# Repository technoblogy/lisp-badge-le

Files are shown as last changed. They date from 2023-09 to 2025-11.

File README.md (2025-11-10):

# Lisp Badge LE
A self-contained low-power computer with its own display and keyboard that you can program in Lisp. It now includes autocomplete, together with the new features in uLisp Release 4.8f.

The files are as follows:

* LispBadgeLE.ino - the uLisp source file for the Lisp Badge LE.
* LispBadgeLE-comments.ino - identical but including comprehensive comments.

Only use one of these files. It should be compiled and uploaded using the Arduino IDE.

For more information see http://www.technoblogy.com/show?3Z2Y.

Note that for consistency with the previous version of the Lisp Badge LE, autocomplete has been assigned to **META-ESC**. If you think that it would be more convenient to have autocomplete on **ESC** and Escape on **META-ESC**, swap the occurrences of '\e' and '\t' in **Keymap[]** before uploading uLisp.

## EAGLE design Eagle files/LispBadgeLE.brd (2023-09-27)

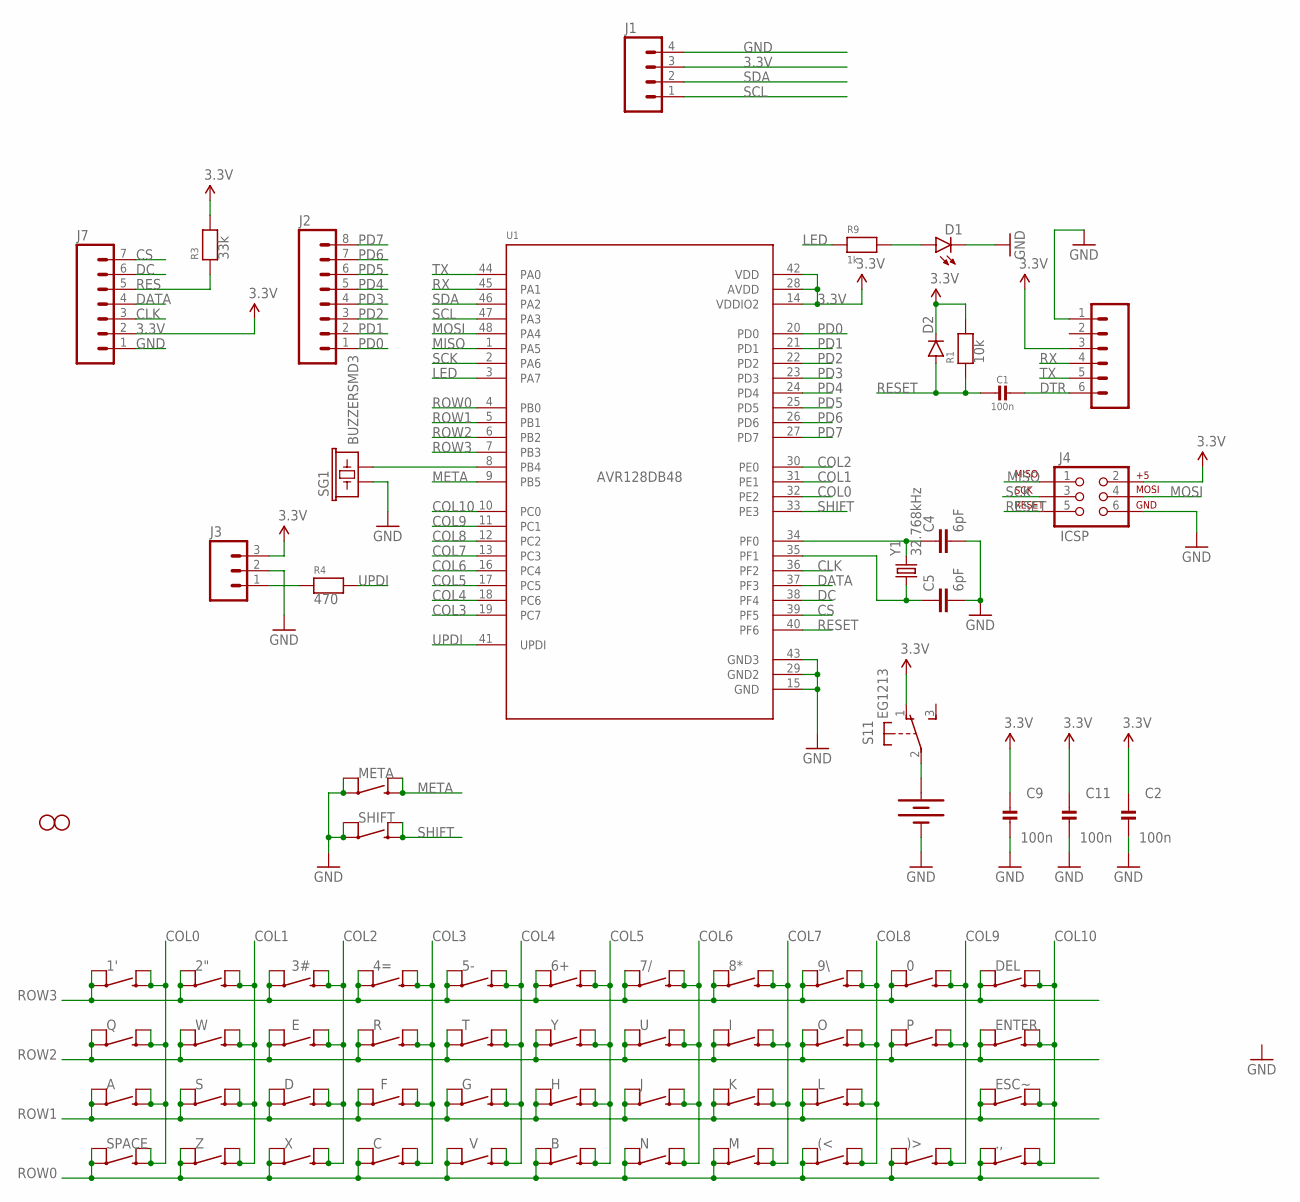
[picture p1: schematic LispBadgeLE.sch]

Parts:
0, 1', 2", 3#, 4=, 5-, 6+, 7/, 8*, 9\\, .,: SWITCH-MOMENTARY-2SMD-4; TACTILE_SWITCH_TALL
(<: SWITCH-MOMENTARY-2SMD-4; TACTILE_SWITCH_TALL
)>: SWITCH-MOMENTARY-2SMD-4; TACTILE_SWITCH_TALL
A: SWITCH-MOMENTARY-2SMD-4; TACTILE_SWITCH_TALL
B: SWITCH-MOMENTARY-2SMD-4; TACTILE_SWITCH_TALL
BAT1: 20mm coincell; BATTCON_20MM_4LEGS
C: SWITCH-MOMENTARY-2SMD-4; TACTILE_SWITCH_TALL
C1, C2, C9, C11: 100n; _0805MP
C4, C5: 6pF; 0805
D: SWITCH-MOMENTARY-2SMD-4; TACTILE_SWITCH_TALL
D1: LED1206-BOTTOM; LED-1206-BOTTOM
D2: DIODESOD123; SOD-123
DEL: SWITCH-MOMENTARY-2SMD-4; TACTILE_SWITCH_TALL
E: SWITCH-MOMENTARY-2SMD-4; TACTILE_SWITCH_TALL
ENTER: SWITCH-MOMENTARY-2SMD-4; TACTILE_SWITCH_TALL
ESC~: SWITCH-MOMENTARY-2SMD-4; TACTILE_SWITCH_TALL
F: SWITCH-MOMENTARY-2SMD-4; TACTILE_SWITCH_TALL
G: SWITCH-MOMENTARY-2SMD-4; TACTILE_SWITCH_TALL
H: SWITCH-MOMENTARY-2SMD-4; TACTILE_SWITCH_TALL
I: SWITCH-MOMENTARY-2SMD-4; TACTILE_SWITCH_TALL
J: SWITCH-MOMENTARY-2SMD-4; TACTILE_SWITCH_TALL
J1: M04LONGPADS; 1X04_LONGPADS
J2: M08LONGPADS; 1X08_LONGPADS
J3: M03LONGPADS; 1X03_LONGPADS
J4: ICSP; 2X3
J7: M07; 1X07
JP1: M06LONGPADS; 1X06_LONGPADS
JP4, JP5: STAND-OFF
K: SWITCH-MOMENTARY-2SMD-4; TACTILE_SWITCH_TALL
L: SWITCH-MOMENTARY-2SMD-4; TACTILE_SWITCH_TALL
M: SWITCH-MOMENTARY-2SMD-4; TACTILE_SWITCH_TALL
META: SWITCH-MOMENTARY-2SMD-4; TACTILE_SWITCH_TALL
N: SWITCH-MOMENTARY-2SMD-4; TACTILE_SWITCH_TALL
O: SWITCH-MOMENTARY-2SMD-4; TACTILE_SWITCH_TALL
P: SWITCH-MOMENTARY-2SMD-4; TACTILE_SWITCH_TALL
Q: SWITCH-MOMENTARY-2SMD-4; TACTILE_SWITCH_TALL
R: SWITCH-MOMENTARY-2SMD-4; TACTILE_SWITCH_TALL
R1: 10k; _0805MP
R3: 33k; _0805MP
R4: 470; _0805MP
R9: 1k; _0805MP
S: SWITCH-MOMENTARY-2SMD-4; TACTILE_SWITCH_TALL
S1: EG1213
SG1: BUZZERSMD3; BUZZER-CMT1102
SHIFT: SWITCH-MOMENTARY-2SMD-4; TACTILE_SWITCH_TALL
SPACE: SWITCH-MOMENTARY-2SMD-4; TACTILE_SWITCH_TALL
T: SWITCH-MOMENTARY-2SMD-4; TACTILE_SWITCH_TALL
U: SWITCH-MOMENTARY-2SMD-4; TACTILE_SWITCH_TALL
U1: AVR128DB48; LQFP48
V: SWITCH-MOMENTARY-2SMD-4; TACTILE_SWITCH_TALL
W: SWITCH-MOMENTARY-2SMD-4; TACTILE_SWITCH_TALL
X: SWITCH-MOMENTARY-2SMD-4; TACTILE_SWITCH_TALL
Y: SWITCH-MOMENTARY-2SMD-4; TACTILE_SWITCH_TALL
Y1: 32.768kHz; CRYSTAL-SMD-3.2X1.5MM
Z: SWITCH-MOMENTARY-2SMD-4; TACTILE_SWITCH_TALL

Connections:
3.3V: C2.1, C9.1, C11.1, D2.C, J1.3, J3.3, J4.2, J7.2, JP1.3, R1.2, R3.2, S1.1 (O), U1.14 (VDDIO2), U1.28 (AVDD), U1.42 (VDD)
CLK: J7.3, U1.36 (PF2)
COL0: 1'.B1 (4), 1'.B2 (2), A.B1 (4), A.B2 (2), Q.B1 (4), Q.B2 (2), SPACE.B1 (4), SPACE.B2 (2), U1.32 (PE2)
COL1: 2".B1 (4), 2".B2 (2), S.B1 (4), S.B2 (2), U1.31 (PE1), W.B1 (4), W.B2 (2), Z.B1 (4), Z.B2 (2)
COL2: 3#.B1 (4), 3#.B2 (2), D.B1 (4), D.B2 (2), E.B1 (4), E.B2 (2), U1.30 (PE0), X.B1 (4), X.B2 (2)
COL3: 4=.B1 (4), 4=.B2 (2), C.B1 (4), C.B2 (2), F.B1 (4), F.B2 (2), R.B1 (4), R.B2 (2), U1.19 (PC7)
COL4: 5-.B1 (4), 5-.B2 (2), G.B1 (4), G.B2 (2), T.B1 (4), T.B2 (2), U1.18 (PC6), V.B1 (4), V.B2 (2)
COL5: 6+.B1 (4), 6+.B2 (2), B.B1 (4), B.B2 (2), H.B1 (4), H.B2 (2), U1.17 (PC5), Y.B1 (4), Y.B2 (2)
COL6: 7/.B1 (4), 7/.B2 (2), J.B1 (4), J.B2 (2), N.B1 (4), N.B2 (2), U.B1 (4), U.B2 (2), U1.16 (PC4)
COL7: 8*.B1 (4), 8*.B2 (2), I.B1 (4), I.B2 (2), K.B1 (4), K.B2 (2), M.B1 (4), M.B2 (2), U1.13 (PC3)
COL8: 9\\.B1 (4), 9\\.B2 (2), (<.B1 (4), (<.B2 (2), L.B1 (4), L.B2 (2), O.B1 (4), O.B2 (2), U1.12 (PC2)
COL9: 0.B1 (4), 0.B2 (2), )>.B1 (4), )>.B2 (2), P.B1 (4), P.B2 (2), U1.11 (PC1)
COL10: .,.B1 (4), .,.B2 (2), DEL.B1 (4), DEL.B2 (2), ENTER.B1 (4), ENTER.B2 (2), ESC~.B1 (4), ESC~.B2 (2), U1.10 (PC0)
CS: J7.7, U1.39 (PF5)
DATA: J7.4, U1.37 (PF3)
DC: J7.6, U1.38 (PF4)
DTR: C1.1, JP1.6
GND: BAT1.NEGATIVE (-), C2.2, C4.2, C5.2, C9.2, C11.2, D1.C, J1.4, J3.2, J4.6, J7.1, JP1.1, META.A1 (3), META.A2 (1), SG1.1, SHIFT.A1 (3), SHIFT.A2 (1), U1.15 (GND), U1.29 (GND2), U1.43 (GND3)
LED: R9.1, U1.3 (PA7)
META: META.B1 (4), META.B2 (2), U1.9 (PB5)
MISO: J4.1, U1.1 (PA5)
MOSI: J4.4, U1.48 (PA4)
unnamed: C5.1, U1.35 (PF1), Y1.P$1 (1)
unnamed: C4.1, U1.34 (PF0), Y1.P$2 (2)
unnamed: D1.A, R9.2
unnamed: BAT1.POSITIVE@1 (+), BAT1.POSITIVE@2 (+), BAT1.POSITIVE@3 (+), BAT1.POSITIVE@4 (+), S1.2
unnamed: SG1.2, U1.8 (PB4)
unnamed: J3.1, R4.1
PD0: J2.1, U1.20 (PD0)
PD1: J2.2, U1.21 (PD1)
PD2: J2.3, U1.22 (PD2)
PD3: J2.4, U1.23 (PD3)
PD4: J2.5, U1.24 (PD4)
PD5: J2.6, U1.25 (PD5)
PD6: J2.7, U1.26 (PD6)
PD7: J2.8, U1.27 (PD7)
RES: J7.5, R3.1
RESET: C1.2, D2.A, J4.5, R1.1, U1.40 (PF6)
ROW0: (<.A1 (3), (<.A2 (1), )>.A1 (3), )>.A2 (1), .,.A1 (3), .,.A2 (1), B.A1 (3), B.A2 (1), C.A1 (3), C.A2 (1), M.A1 (3), M.A2 (1), N.A1 (3), N.A2 (1), SPACE.A1 (3), SPACE.A2 (1), U1.4 (PB0), V.A1 (3), V.A2 (1), X.A1 (3), X.A2 (1), Z.A1 (3), Z.A2 (1)
ROW1: A.A1 (3), A.A2 (1), D.A1 (3), D.A2 (1), ESC~.A1 (3), ESC~.A2 (1), F.A1 (3), F.A2 (1), G.A1 (3), G.A2 (1), H.A1 (3), H.A2 (1), J.A1 (3), J.A2 (1), K.A1 (3), K.A2 (1), L.A1 (3), L.A2 (1), S.A1 (3), S.A2 (1), U1.5 (PB1)
ROW2: E.A1 (3), E.A2 (1), ENTER.A1 (3), ENTER.A2 (1), I.A1 (3), I.A2 (1), O.A1 (3), O.A2 (1), P.A1 (3), P.A2 (1), Q.A1 (3), Q.A2 (1), R.A1 (3), R.A2 (1), T.A1 (3), T.A2 (1), U.A1 (3), U.A2 (1), U1.6 (PB2), W.A1 (3), W.A2 (1), Y.A1 (3), Y.A2 (1)
ROW3: 0.A1 (3), 0.A2 (1), 1'.A1 (3), 1'.A2 (1), 2".A1 (3), 2".A2 (1), 3#.A1 (3), 3#.A2 (1), 4=.A1 (3), 4=.A2 (1), 5-.A1 (3), 5-.A2 (1), 6+.A1 (3), 6+.A2 (1), 7/.A1 (3), 7/.A2 (1), 8*.A1 (3), 8*.A2 (1), 9\\.A1 (3), 9\\.A2 (1), DEL.A1 (3), DEL.A2 (1), U1.7 (PB3)
RX: JP1.4, U1.45 (PA1)
SCK: J4.3, U1.2 (PA6)
SCL: J1.1, U1.47 (PA3)
SDA: J1.2, U1.46 (PA2)
SHIFT: SHIFT.B1 (4), SHIFT.B2 (2), U1.33 (PE3)
TX: JP1.5, U1.44 (PA0)
UPDI: R4.2, U1.41 (UPDI)

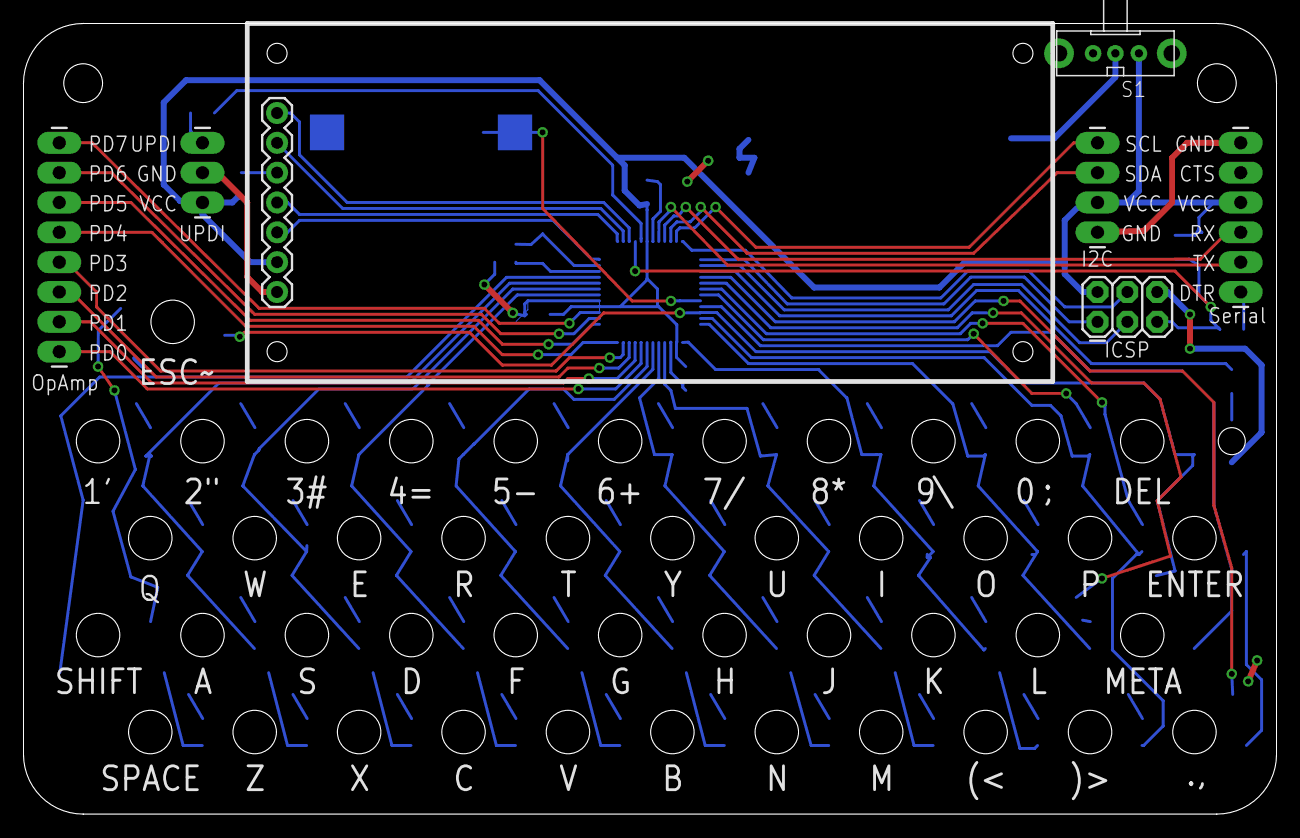
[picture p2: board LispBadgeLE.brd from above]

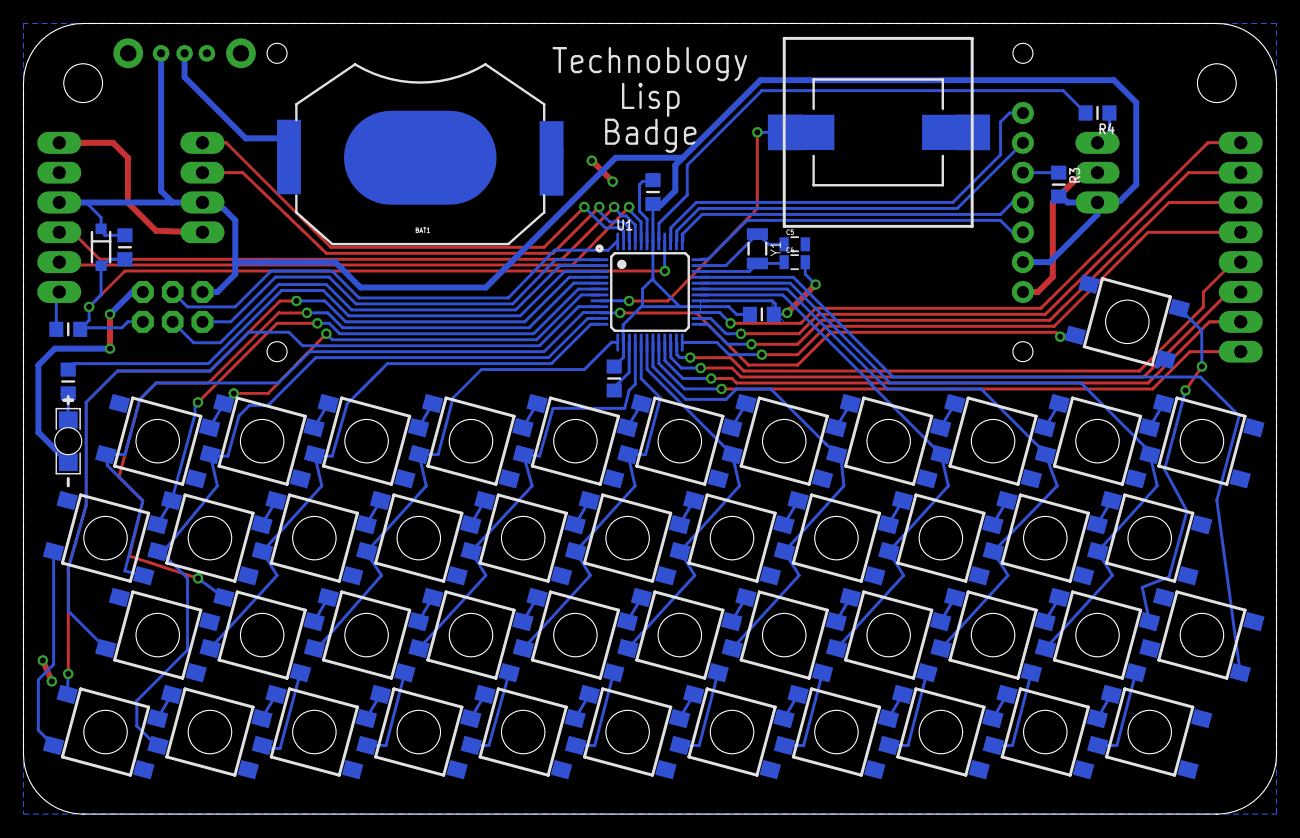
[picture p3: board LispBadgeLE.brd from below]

Board: 2 copper layers, 106.7 x 67.3 mm, 70 parts (61 on the bottom side), 49 nets.

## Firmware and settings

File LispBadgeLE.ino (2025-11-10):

/* Lisp Badge LE Release 4.8f - www.ulisp.com
   David Johnson-Davies - www.technoblogy.com - 9th November 2025

   Licensed under the MIT license: https://opensource.org/licenses/MIT
*/

// Lisp Library
const char LispLibrary[] PROGMEM = "";

// Compile options

#define checkoverflow
// #define resetautorun
#define printfreespace
#define serialmonitor
// #define printgcs
// #define sdcardsupport
// #define lisplibrary
#define assemblerlist
// #define extensions

// Includes

// #include "LispLibrary.h"
#include <avr/sleep.h>
#include <setjmp.h>
#include <SPI.h>
#include <limits.h>

#if defined(sdcardsupport)
#include <SD.h>
#define SDSIZE 172
#else
#define SDSIZE 0
#endif

// Platform specific settings

#define WORDALIGNED __attribute__((aligned (2)))
#define OBJECTALIGNED __attribute__((aligned (4)))
#define BUFFERSIZE 22                     /* longest builtin name + 1 */

#if defined(__AVR_AVR128DA48__) || defined(__AVR_AVR128DB48__)  /* LispBadge LE */
  #include <Flash.h>
  #define WORKSPACESIZE (2795-SDSIZE)     /* Objects (4*bytes) */
  #define FLASHWRITESIZE 16384            /* Bytes */
  #define CODESIZE 96                     /* Bytes <= 512 */
  #define STACKDIFF 320
  #define CPU_AVR128DX48
  #undef  LED_BUILTIN
  #define LED_BUILTIN 7
  #define SDCARD_SS_PIN 10
  #define SHIFT_KEY 33
  #define META_KEY 13
  const uint8_t xsize = 250, ysize = 122, ymax = 121;

#else
#error "Board not supported!"
#endif

// C Macros

#define nil                NULL
#define car(x)             (((object *) (x))->car)
#define cdr(x)             (((object *) (x))->cdr)

#define first(x)           car(x)
#define rest(x)            cdr(x)
#define second(x)          first(rest(x))
#define cddr(x)            cdr(cdr(x))
#define third(x)           first(cddr(x))

#define push(x, y)         ((y) = cons((x),(y)))
#define pop(y)             ((y) = cdr(y))

#define protect(y)         push((y), GCStack)
#define unprotect()        pop(GCStack)

#define integerp(x)        ((x) != NULL && (x)->type == NUMBER)
#define symbolp(x)         ((x) != NULL && (x)->type == SYMBOL)
#define stringp(x)         ((x) != NULL && (x)->type == STRING)
#define characterp(x)      ((x) != NULL && (x)->type == CHARACTER)
#define arrayp(x)          ((x) != NULL && (x)->type == ARRAY)
#define streamp(x)         ((x) != NULL && (x)->type == STREAM)

#define mark(x)            (car(x) = (object *)(((uintptr_t)(car(x))) | MARKBIT))
#define unmark(x)          (car(x) = (object *)(((uintptr_t)(car(x))) & ~MARKBIT))
#define marked(x)          ((((uintptr_t)(car(x))) & MARKBIT) != 0)
#define MARKBIT            1

#define setflag(x)         (Flags = Flags | 1<<(x))
#define clrflag(x)         (Flags = Flags & ~(1<<(x)))
#define tstflag(x)         (Flags & 1<<(x))

#define issp(x)            (x == ' ' || x == '\n' || x == '\r' || x == '\t')
#define isbr(x)            (x == ')' || x == '(' || x == '"' || x == '#' || x == '\'')
#define fntype(x)          (getminmax((uint16_t)(x))>>6)
#define longsymbolp(x)     (((x)->name & 0x03) == 0)
#define longnamep(x)       (((x) & 0x03) == 0)
#define twist(x)           ((uint16_t)((x)<<2) | (((x) & 0xC000)>>14))
#define untwist(x)         (((x)>>2 & 0x3FFF) | ((x) & 0x03)<<14)
#define arraysize(x)       (sizeof(x) / sizeof(x[0]))
#define stringifyX(x)      #x
#define stringify(x)       stringifyX(x)
#define PACKEDS            17600
#define BUILTINS           64000
#define ENDFUNCTIONS       1536

// Code marker stores start and end of code block (max 256 bytes)
#define startblock(x)      ((x->integer) & 0xFF)
#define endblock(x)        ((x->integer) >> 8 & 0xFF)

// Constants

#define USERSTREAMS        16
#define TRACEMAX 3  // Maximum number of traced functions
enum type { ZZERO=0, SYMBOL=2, CODE=4, NUMBER=6, STREAM=8, CHARACTER=10, ARRAY=12, STRING=14, PAIR=16 };  // ARRAY STRING and PAIR must be last
enum token { UNUSED, BRA, KET, QUO, DOT };
enum fntypes_t { OTHER_FORMS, TAIL_FORMS, FUNCTIONS, SPECIAL_FORMS };

// Typedefs

typedef uint16_t symbol_t;
typedef uint16_t builtin_t;
typedef uint16_t chars_t;

typedef struct sobject {
  union {
    struct {
      sobject *car;
      sobject *cdr;
    };
    struct {
      unsigned int type;
      union {
        symbol_t name;
        int integer;
        chars_t chars; // For strings
      };
    };
  };
} object;

typedef object *(*fn_ptr_type)(object *, object *);
typedef void (*mapfun_t)(object *, object **);
typedef int (*intfn_ptr_type)(int w, int x, int y, int z);

typedef const struct {
  const char *string;
  fn_ptr_type fptr;
  uint8_t minmax;
  const char *doc;
} tbl_entry_t;

// Stream typedefs

typedef uint8_t nstream_t;

typedef int (*gfun_t)();
typedef void (*pfun_t)(char);

typedef pfun_t (*pstream_ptr_t)(uint8_t address);
typedef gfun_t (*gstream_ptr_t)(uint8_t address);

typedef const struct {
  const char *streamname;
  pstream_ptr_t pfunptr;
  gstream_ptr_t gfunptr;
} stream_entry_t;

enum builtins: builtin_t { NIL, TEE, NOTHING, OPTIONAL, FEATURES, INITIALELEMENT, ELEMENTTYPE, TEST, COLONA, COLONB,
COLONC, BIT, AMPREST, LAMBDA, LET, LETSTAR, CLOSURE, PSTAR, QUOTE, DEFUN, DEFVAR, DEFCODE, EQ, CAR, FIRST,
CDR, REST, NTH, AREF, CHAR, STRINGFN, PINMODE, DIGITALWRITE, ANALOGREAD, ANALOGREFERENCE, REGISTER,
FORMAT, 
 };

// Global variables

uint8_t FLAG __attribute__ ((section (".noinit")));

object Workspace[WORKSPACESIZE] OBJECTALIGNED;
#if defined(CODESIZE)
uint8_t MyCode[CODESIZE] WORDALIGNED; // Must be even
#endif

jmp_buf toplevel_handler;
jmp_buf *handler = &toplevel_handler;
unsigned int Freespace = 0;
object *Freelist;
unsigned int I2Ccount;
unsigned int TraceFn[TRACEMAX];
unsigned int TraceDepth[TRACEMAX];
builtin_t Context;
#define BACKTRACESIZE 8
uint8_t TraceStart = 0, TraceTop = 0;
symbol_t Backtrace[BACKTRACESIZE];

object *GlobalEnv;
object *GCStack = NULL;
object *GlobalString;
object *GlobalStringTail;
int GlobalStringIndex = 0;
uint8_t PrintCount = 0;
uint8_t BreakLevel = 0;
char LastChar = 0;
char LastPrint = 0;
uint16_t RandomSeed;

// Flags
enum flag { PRINTREADABLY, RETURNFLAG, ESCAPE, EXITEDITOR, LIBRARYLOADED, NOESC, NOECHO, MUFFLEERRORS, BACKTRACE };
typedef uint16_t flags_t;
flags_t Flags = 1<<PRINTREADABLY; // Set by default

// Forward references
object *tee;
void pfstring (PGM_P s, pfun_t pfun);

// Error handling

int modbacktrace (int n) {
  return (n+BACKTRACESIZE) % BACKTRACESIZE;
}

void printbacktrace () {
  if (TraceStart != TraceTop) pserial('[');
  int tracesize = modbacktrace(TraceTop-TraceStart);
  for (int i=1; i<=tracesize; i++) {
    printsymbol(symbol(Backtrace[modbacktrace(TraceTop-i)]), pserial);
    if (i!=tracesize) pfstring(PSTR(" <- "), pserial);
  }
  if (TraceStart != TraceTop) pserial(']');
}

void errorsub (symbol_t fname, PGM_P string) {
  pfl(pserial); pfstring(PSTR("Error"), pserial);
  if (TraceStart != TraceTop) pserial(' ');
  printbacktrace();
  pfstring(PSTR(": "), pserial);
  if (fname != sym(NIL)) {
    pserial('\'');
    psymbol(fname, pserial);
    pserial('\''); pserial(' ');
  }
  pfstring(string, pserial);
}

void errorend () { GCStack = NULL; longjmp(*handler, 1); }

void errorsym (symbol_t fname, PGM_P string, object *symbol) {
  if (!tstflag(MUFFLEERRORS)) {
    errorsub(fname, string);
    pserial(':'); pserial(' ');
    printobject(symbol, pserial);
    pln(pserial);
  }
  errorend();
}

void errorsym2 (symbol_t fname, PGM_P string) {
  if (!tstflag(MUFFLEERRORS)) {
    errorsub(fname, string);
    pln(pserial);
  }
  errorend();
}

void error (PGM_P string, object *symbol) {
  errorsym(sym(Context), string, symbol);
}

void error2 (PGM_P string) {
  errorsym2(sym(Context), string);
}

void formaterr (object *formatstr, PGM_P string, uint8_t p) {
  pln(pserial); indent(4, ' ', pserial); printstring(formatstr, pserial); pln(pserial);
  indent(p+5, ' ', pserial); pserial('^');
  error2(string);
  pln(pserial);
  errorend();
}

// Save space as these are used multiple times
const char notanumber[] PROGMEM = "argument is not a number";
const char notaninteger[] PROGMEM = "argument is not an integer";
const char notastring[] PROGMEM = "argument is not a string";
const char notalist[] PROGMEM = "argument is not a list";
const char notasymbol[] PROGMEM = "argument is not a symbol";
const char notproper[] PROGMEM = "argument is not a proper list";
const char toomanyargs[] PROGMEM = "too many arguments";
const char toofewargs[] PROGMEM = "too few arguments";
const char noargument[] PROGMEM = "missing argument";
const char nostream[] PROGMEM = "missing stream argument";
const char overflow[] PROGMEM = "arithmetic overflow";
const char divisionbyzero[] PROGMEM = "division by zero";
const char indexnegative[] PROGMEM = "index can't be negative";
const char invalidarg[] PROGMEM = "invalid argument";
const char invalidkey[] PROGMEM = "invalid keyword";
const char illegalclause[] PROGMEM = "illegal clause";
const char illegalfn[] PROGMEM = "illegal function";
const char invalidpin[] PROGMEM = "invalid pin";
const char oddargs[] PROGMEM = "odd number of arguments";
const char indexrange[] PROGMEM = "index out of range";
const char canttakecar[] PROGMEM = "can't take car";
const char canttakecdr[] PROGMEM = "can't take cdr";
const char unknownstreamtype[] PROGMEM = "unknown stream type";

// Set up workspace

void initworkspace () {
  Freelist = NULL;
  for (int i=WORKSPACESIZE-1; i>=0; i--) {
    object *obj = &Workspace[i];
    car(obj) = NULL;
    cdr(obj) = Freelist;
    Freelist = obj;
    Freespace++;
  }
}

object *myalloc () {
  if (Freespace == 0) { Context = NIL; error2(PSTR("no room")); }
  object *temp = Freelist;
  Freelist = cdr(Freelist);
  Freespace--;
  return temp;
}

inline void myfree (object *obj) {
  car(obj) = NULL;
  cdr(obj) = Freelist;
  Freelist = obj;
  Freespace++;
}

// Make each type of object

object *number (int n) {
  object *ptr = myalloc();
  ptr->type = NUMBER;
  ptr->integer = n;
  return ptr;
}

object *character (uint8_t c) {
  object *ptr = myalloc();
  ptr->type = CHARACTER;
  ptr->chars = c;
  return ptr;
}

object *cons (object *arg1, object *arg2) {
  object *ptr = myalloc();
  ptr->car = arg1;
  ptr->cdr = arg2;
  return ptr;
}

object *symbol (symbol_t name) {
  object *ptr = myalloc();
  ptr->type = SYMBOL;
  ptr->name = name;
  return ptr;
}

inline object *bsymbol (builtin_t name) {
  return intern(twist(name+BUILTINS));
}

object *codehead (int entry) {
  object *ptr = myalloc();
  ptr->type = CODE;
  ptr->integer = entry;
  return ptr;
}

object *intern (symbol_t name) {
  for (int i=0; i<WORKSPACESIZE; i++) {
    object *obj = &Workspace[i];
    if (obj->type == SYMBOL && obj->name == name) return obj;
  }
  return symbol(name);
}

bool eqsymbols (object *obj, char *buffer) {
  object *arg = cdr(obj);
  int i = 0;
  while (!(arg == NULL && buffer[i] == 0)) {
    if (arg == NULL || buffer[i] == 0) return false;
    chars_t test = 0; int shift = 8;
    for (int j=0; j<2; j++, i++) {
      if (buffer[i] == 0) break;
      test = test | buffer[i]<<shift;
      shift = shift - 8;
    }
    if (arg->chars != test) return false;
    arg = car(arg);
  }
  return true;
}

object *internlong (char *buffer) {
  for (int i=0; i<WORKSPACESIZE; i++) {
    object *obj = &Workspace[i];
    if (obj->type == SYMBOL && longsymbolp(obj) && eqsymbols(obj, buffer)) return obj;
  }
  object *obj = lispstring(buffer);
  obj->type = SYMBOL;
  return obj;
}

object *stream (uint8_t streamtype, uint8_t address) {
  object *ptr = myalloc();
  ptr->type = STREAM;
  ptr->integer = streamtype<<8 | address;
  return ptr;
}

object *newstring () {
  object *ptr = myalloc();
  ptr->type = STRING;
  ptr->chars = 0;
  return ptr;
}

// Features

const char arrays[] PROGMEM = ":arrays";
const char doc[] PROGMEM = ":documentation";
const char machinecode[] PROGMEM = ":machine-code";
const char errorhandling[] PROGMEM = ":error-handling";
const char sdcard[] PROGMEM = ":sd-card";

char *copyprogmemstring (PGM_P s, char *buffer) {
  int max = BUFFERSIZE-1;
  int i = 0;
  do {
    char c = pgm_read_byte(s++);
    buffer[i++] = c;
    if (c == 0) break;
  } while (i<max);
  return buffer;
}

object *features () {
  char buffer[BUFFERSIZE];
  object *result = NULL;
  #if defined(sdcardsupport)
  push(internlong(copyprogmemstring(sdcard, buffer)), result);
  #endif
  push(internlong(copyprogmemstring(errorhandling, buffer)), result);
  #if defined(CODESIZE)
  push(internlong(copyprogmemstring(machinecode, buffer)), result);
  #endif
  push(internlong(copyprogmemstring(doc, buffer)), result);
  push(internlong(copyprogmemstring(arrays, buffer)), result);
  return result;
}

// Garbage collection

void markobject (object *obj) {
  MARK:
  if (obj == NULL) return;
  if (marked(obj)) return;

  object* arg = car(obj);
  unsigned int type = obj->type;
  mark(obj);

  if (type >= PAIR || type == ZZERO) { // cons
    markobject(arg);
    obj = cdr(obj);
    goto MARK;
  }

  if (type == ARRAY) {
    obj = cdr(obj);
    goto MARK;
  }

  if ((type == STRING) || (type == SYMBOL && longsymbolp(obj))) {
    obj = cdr(obj);
    while (obj != NULL) {
      arg = car(obj);
      mark(obj);
      obj = arg;
    }
  }
}

void sweep () {
  Freelist = NULL;
  Freespace = 0;
  for (int i=WORKSPACESIZE-1; i>=0; i--) {
    object *obj = &Workspace[i];
    if (!marked(obj)) myfree(obj); else unmark(obj);
  }
}

void gc (object *form, object *env) {
  #if defined(printgcs)
  int start = Freespace;
  #endif
  markobject(tee);
  markobject(GlobalEnv);
  markobject(GCStack);
  markobject(form);
  markobject(env);
  sweep();
  #if defined(printgcs)
  pfl(pserial); pserial('{'); pint(Freespace - start, pserial); pserial('}');
  #endif
}

// Compact image

void movepointer (object *from, object *to) {
  uintptr_t limit = ((uintptr_t)(from) - (uintptr_t)(Workspace))/sizeof(object);
  for (uintptr_t i=0; i<=limit; i++) {
    object *obj = &Workspace[i];
    unsigned int type = (obj->type) & ~MARKBIT;
    if (marked(obj) && (type >= ARRAY || type==ZZERO || (type == SYMBOL && longsymbolp(obj)))) {
      if (car(obj) == (object *)((uintptr_t)from | MARKBIT))
        car(obj) = (object *)((uintptr_t)to | MARKBIT);
      if (cdr(obj) == from) cdr(obj) = to;
    }
  }
  // Fix strings and long symbols
  for (uintptr_t i=0; i<=limit; i++) {
    object *obj = &Workspace[i];
    if (marked(obj)) {
      unsigned int type = (obj->type) & ~MARKBIT;
      if (type == STRING || (type == SYMBOL && longsymbolp(obj))) {
        obj = cdr(obj);
        while (obj != NULL) {
          if (cdr(obj) == to) cdr(obj) = from;
          obj = (object *)((uintptr_t)(car(obj)) & ~MARKBIT);
        }
      }
    }
  }
}

uintptr_t compactimage (object **arg) {
  markobject(tee);
  markobject(GlobalEnv);
  markobject(GCStack);
  object *firstfree = Workspace;
  while (marked(firstfree)) firstfree++;
  object *obj = &Workspace[WORKSPACESIZE-1];
  while (firstfree < obj) {
    if (marked(obj)) {
      car(firstfree) = car(obj);
      cdr(firstfree) = cdr(obj);
      unmark(obj);
      movepointer(obj, firstfree);
      if (GlobalEnv == obj) GlobalEnv = firstfree;
      if (GCStack == obj) GCStack = firstfree;
      if (*arg == obj) *arg = firstfree;
      while (marked(firstfree)) firstfree++;
    }
    obj--;
  }
  sweep();
  return firstfree - Workspace;
}

// Make SD card filename

char *MakeFilename (object *arg, char *buffer) {
  int max = BUFFERSIZE-1;
  int i = 0;
  do {
    char c = nthchar(arg, i);
    if (c == '\0') break;
    buffer[i++] = c;
  } while (i<max);
  buffer[i] = '\0';
  return buffer;
}

// Save-image and load-image

#if defined(sdcardsupport)

void SDBegin () {
  SD.begin(SDCARD_SS_PIN);
}

void SDWriteInt (File file, int data) {
  file.write(data & 0xFF); file.write(data>>8 & 0xFF);
}

int SDReadInt (File file) {
  uint8_t b0 = file.read(); uint8_t b1 = file.read();
  return b0 | b1<<8;
}
#elif defined(FLASHWRITESIZE)
#if defined (CPU_ATmega1284P)
// save-image area is the 15872 bytes (31 x 512-byte pages) from 0x1c000 to 0x1FE00
const uint32_t BaseAddress = 0x1c000;
uint8_t FlashCheck() {
  return 0;
}

void FlashWriteInt (uint32_t *addr, int data) {
  if (((*addr) & 0xFF) == 0) optiboot_page_erase(BaseAddress + ((*addr) & 0xFF00));
  optiboot_page_fill(BaseAddress + *addr, data);
  if (((*addr) & 0xFF) == 0xFE) optiboot_page_write(BaseAddress + ((*addr) & 0xFF00));
  (*addr)++; (*addr)++;
}

void FlashEndWrite (uint32_t *addr) {
  if (((*addr) & 0xFF) != 0) optiboot_page_write((BaseAddress + ((*addr) & 0xFF00)));
}

uint8_t FlashReadByte (uint32_t *addr) {
  return pgm_read_byte_far(BaseAddress + (*addr)++);
}

int FlashReadInt (uint32_t *addr) {
  int data = pgm_read_word_far(BaseAddress + *addr);
  (*addr)++; (*addr)++;
  return data;
}
#elif defined (CPU_AVR128DX32) || defined (CPU_AVR128DX48)
// save-image area is the 15872 bytes (31 x 512-byte pages) from 0x1c000 to 0x1FE00
const uint32_t BaseAddress = 0x1c000;
uint8_t FlashCheck() {
  return Flash.checkWritable();
}

void FlashWriteInt (uint32_t *addr, int data) {
  if (((*addr) & 0x1FF) == 0) Flash.erasePage(BaseAddress + ((*addr) & 0xFE00));
  Flash.writeWord(BaseAddress + *addr, data);
  (*addr)++; (*addr)++;
}

void FlashEndWrite (uint32_t *addr) {
  (void) addr;
}

uint8_t FlashReadByte (uint32_t *addr) {
  return Flash.readByte(BaseAddress + (*addr)++);
}

int FlashReadInt (uint32_t *addr) {
  int data = Flash.readWord(BaseAddress + *addr);
  (*addr)++; (*addr)++;
  return data;
}
#endif
#else
void EEPROMWriteInt (unsigned int *addr, int data) {
  EEPROM.write((*addr)++, data & 0xFF); EEPROM.write((*addr)++, data>>8 & 0xFF);
}

int EEPROMReadInt (unsigned int *addr) {
  uint8_t b0 = EEPROM.read((*addr)++); uint8_t b1 = EEPROM.read((*addr)++);
  return b0 | b1<<8;
}
#endif

unsigned int saveimage (object *arg) {
#if defined(sdcardsupport)
  unsigned int imagesize = compactimage(&arg);
  SDBegin();
  File file;
  if (stringp(arg)) {
    char buffer[BUFFERSIZE];
    file = SD.open(MakeFilename(arg, buffer), O_RDWR | O_CREAT | O_TRUNC);
    if (!file) error2(PSTR("problem saving to SD card or invalid filename"));
    arg = NULL;
  } else if (arg == NULL || listp(arg)) {
    file = SD.open("/ULISP.IMG", O_RDWR | O_CREAT | O_TRUNC);
    if (!file) error2(PSTR("problem saving to SD card"));
  }
  else error(invalidarg, arg);
  SDWriteInt(file, (uintptr_t)arg);
  SDWriteInt(file, imagesize);
  SDWriteInt(file, (uintptr_t)GlobalEnv);
  SDWriteInt(file, (uintptr_t)GCStack);
  #if defined(CODESIZE)
  for (int i=0; i<CODESIZE; i++) file.write(MyCode[i]);
  #endif
  for (unsigned int i=0; i<imagesize; i++) {
    object *obj = &Workspace[i];
    SDWriteInt(file, (uintptr_t)car(obj));
    SDWriteInt(file, (uintptr_t)cdr(obj));
  }
  file.close();
  return imagesize;
#elif defined(FLASHWRITESIZE)
  unsigned int imagesize = compactimage(&arg);
  if (!(arg == NULL || listp(arg))) error(invalidarg, arg);
  if (FlashCheck()) error2(PSTR("flash write not supported"));
  // Save to Flash
  #if defined(CODESIZE)
  int bytesneeded = 10 + CODESIZE + imagesize*4;
  #else
  int bytesneeded = 10 + imagesize*4;
  #endif
  if (bytesneeded > FLASHWRITESIZE) error(PSTR("image too large"), number(imagesize));
  uint32_t addr = 0;
  FlashWriteInt(&addr, (uintptr_t)arg);
  FlashWriteInt(&addr, imagesize);
  FlashWriteInt(&addr, (uintptr_t)GlobalEnv);
  FlashWriteInt(&addr, (uintptr_t)GCStack);
  #if defined(CODESIZE)
  for (int i=0; i<CODESIZE/2; i++) FlashWriteInt(&addr, MyCode[i*2] | MyCode[i*2+1]<<8);
  #endif
  for (unsigned int i=0; i<imagesize; i++) {
    object *obj = &Workspace[i];
    FlashWriteInt(&addr, (uintptr_t)car(obj));
    FlashWriteInt(&addr, (uintptr_t)cdr(obj));
  }
  FlashEndWrite(&addr);
  return imagesize;
#elif defined(EEPROMSIZE)
  unsigned int imagesize = compactimage(&arg);
  if (!(arg == NULL || listp(arg))) error(invalidarg, arg);
  int bytesneeded = imagesize*4 + 10;
  if (bytesneeded > EEPROMSIZE) error(PSTR("image too large"), number(imagesize));
  unsigned int addr = 0;
  EEPROMWriteInt(&addr, (unsigned int)arg);
  EEPROMWriteInt(&addr, imagesize);
  EEPROMWriteInt(&addr, (unsigned int)GlobalEnv);
  EEPROMWriteInt(&addr, (unsigned int)GCStack);
  for (unsigned int i=0; i<imagesize; i++) {
    object *obj = &Workspace[i];
    EEPROMWriteInt(&addr, (uintptr_t)car(obj));
    EEPROMWriteInt(&addr, (uintptr_t)cdr(obj));
  }
  return imagesize;
#else
  (void) arg;
  error2(PSTR("not available"));
  return 0;
#endif
}
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
void loop () {
  if (!setjmp(toplevel_handler)) {
    #if defined(resetautorun)
    volatile int autorun = 12; // Fudge to keep code size the same
    #else
    volatile int autorun = 13;
    #endif
    if (autorun == 12) autorunimage();
  }
  ulisperror();
  repl(NULL);
}

void ulisperror () {
  // Come here after error
  #if defined (serialmonitor)
  delay(100); while (Serial.available()) Serial.read();
  #endif
  clrflag(NOESC); BreakLevel = 0; TraceStart = 0; TraceTop = 0;
  for (int i=0; i<TRACEMAX; i++) TraceDepth[i] = 0;
  #if defined(sdcardsupport)
  SDpfile.close(); SDgfile.close();
  #endif
  #if defined(lisplibrary)
  if (!tstflag(LIBRARYLOADED)) { setflag(LIBRARYLOADED); loadfromlibrary(NULL); clrflag(NOECHO); }
  #endif
}

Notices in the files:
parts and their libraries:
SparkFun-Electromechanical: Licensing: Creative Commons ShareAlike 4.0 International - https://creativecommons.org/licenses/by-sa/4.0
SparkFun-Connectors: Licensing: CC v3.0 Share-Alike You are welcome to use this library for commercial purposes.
